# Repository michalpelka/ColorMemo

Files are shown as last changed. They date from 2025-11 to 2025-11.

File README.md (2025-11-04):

# ColorMemo


An open-source, handheld color memory game built around a WeMos D1 mini (ESP8266), a 3×4 push-button matrix, a 12‑pixel NeoPixel (WS2812) LED array, and a small buzzer. 
Power it up, memorize the brief color reveal, and then flip tiles two at a time to find matching pairs. Clear the board to win and enjoy the victory animation and melody.

## Photos

Below are a few snapshots of the prototype and assembly. Images are stored in `Photos/`.

<div align="center">
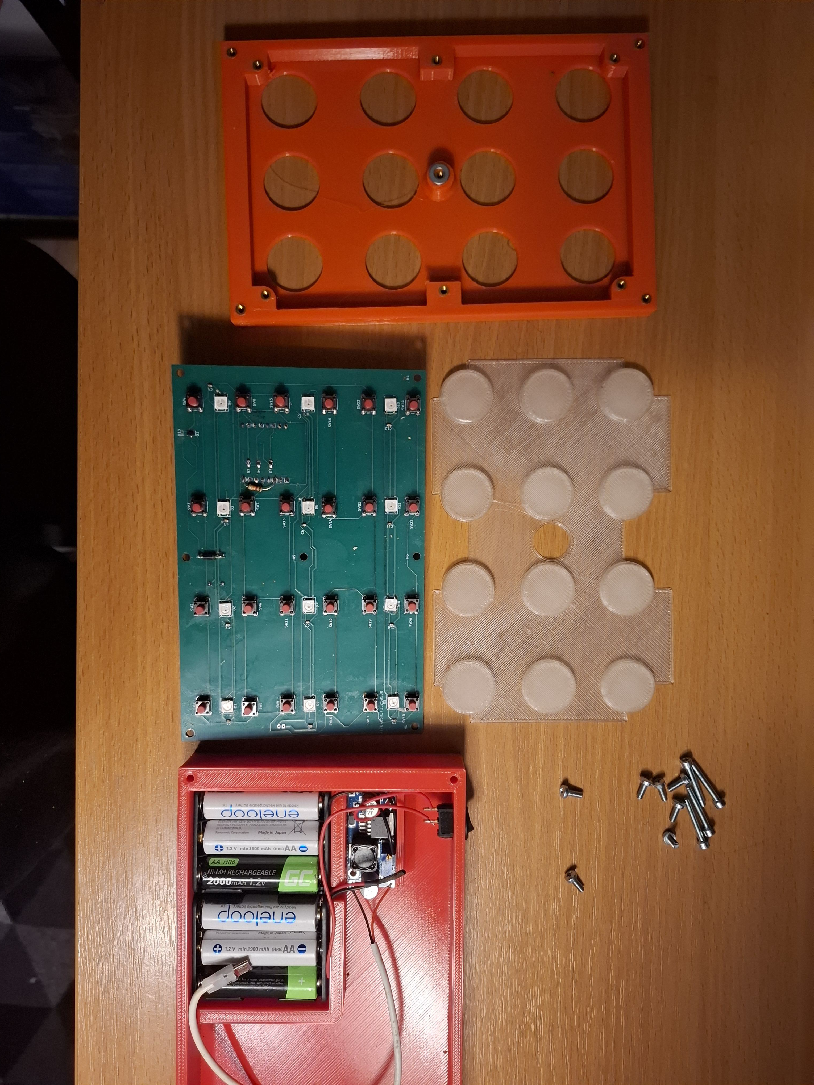
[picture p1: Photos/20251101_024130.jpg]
Assembly 2025-11-01 02:41
  
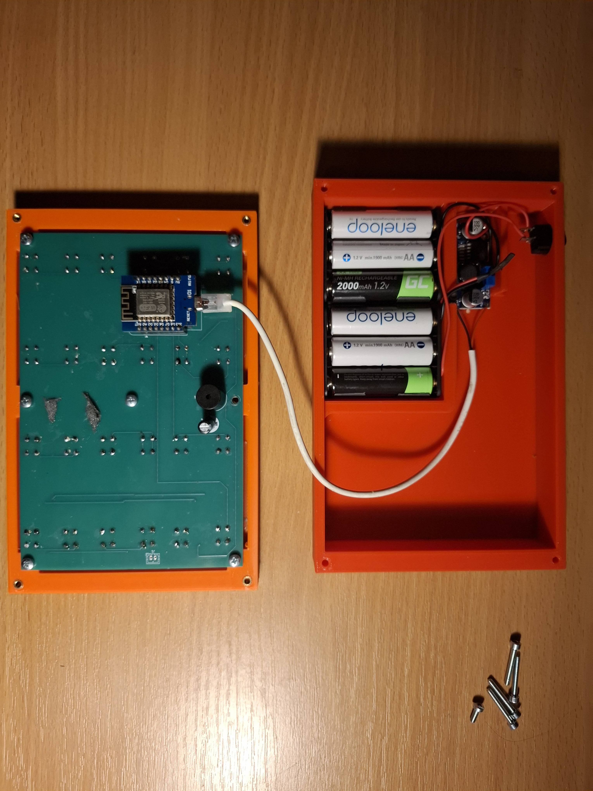
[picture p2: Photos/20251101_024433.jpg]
Assembly 2025-11-01 02:44
  
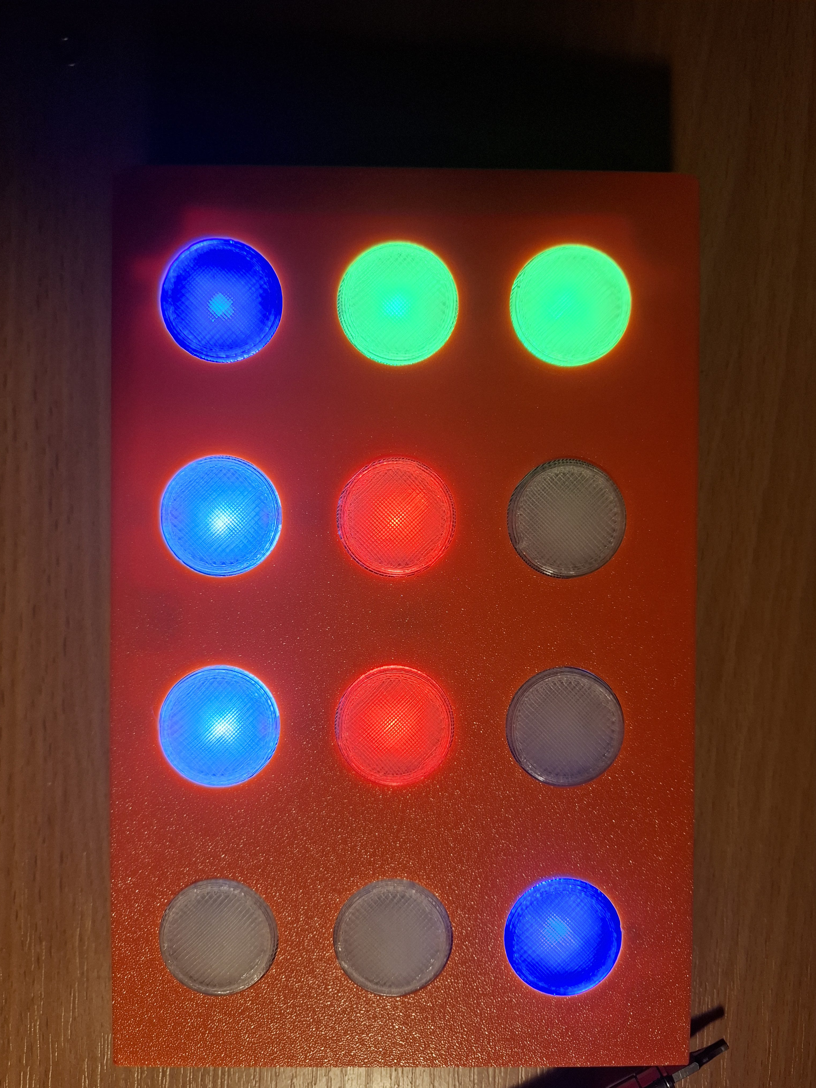
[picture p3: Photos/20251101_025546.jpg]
Assembly 2025-11-01 02:55
     
</div>

<div align="center">
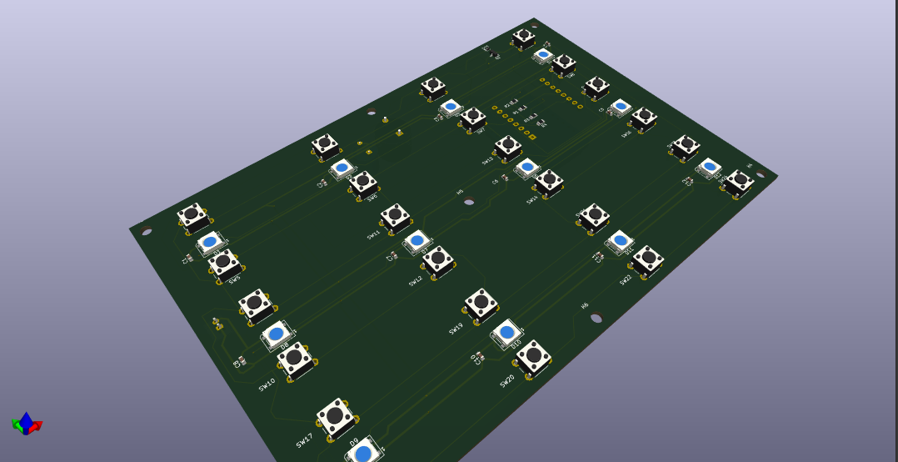
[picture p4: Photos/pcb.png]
  
</div>

## Repository structure

- `Firmware/` — PlatformIO project with Arduino firmware for ESP8266 (D1 mini lite) using Adafruit NeoPixel.
- `KiCad/` — Complete PCB design (schematic, PCB, STEP) and production files (`gerber/`).
- `3DPrint/` — 3D printable parts for enclosure and/or fixtures.
- `Cad/` — Additional mechanical CAD sources.
- `Photos/` — Renders or placement guides.
- `LICENSE` — Project license.

## Hardware overview

- MCU: WeMos D1 mini lite (ESP8266)
- LEDs: 12× WS2812/NeoPixel (strip or array)
- Inputs: 12 momentary push buttons arranged as a 3×4 matrix (row/column scanned)
- Audio: Passive buzzer for tones and win melody

The firmware scans a 3×4 button matrix while driving a 12‑LED NeoPixel strip. On boot, it shuffles 6 color pairs, briefly reveals all 12 tiles with tones, and then hides them. Press two buttons; if the colors match, they stay lit. Match all pairs to win.

### Pinout (D1 mini lite)

- NeoPixel DIN: D1 (GPIO5)
- Buzzer: D2 (GPIO4)
- Button matrix rows (outputs):
  - ROW0: D8 (GPIO15)
  - ROW1: D3 (GPIO0)
  - ROW2: D4 (GPIO2)
- Button matrix columns (inputs with pull‑ups):
  - COL0: D0 (GPIO16)
  - COL1: D7 (GPIO13)
  - COL2: D6 (GPIO12)
  - COL3: D5 (GPIO14)
- A0 (ADC) is sampled at boot to add entropy for shuffling.

Notes:
- Columns use `INPUT_PULLUP`; a pressed button reads LOW when its row is driven active (LOW).
- The firmware maps physical grid positions to LED indices to keep the visual grid coherent.

### Bill of materials (BOM)

- KiCad BOM
- 2x3AA battery holder
- Cheap step down LM965 
- USB cable to cut 

## Firmware

The firmware lives in `Firmware/` and is a PlatformIO project.

- Board environment: `d1_mini_lite`
- Platform: `espressif8266`
- Framework: `arduino`
- Dependency: `Adafruit NeoPixel`

### Quick start (PlatformIO CLI)

1. Install PlatformIO Core (CLI): https://platformio.org/install/cli
2. From the repository root (or `Firmware/`):
   - Build: `pio run -e d1_mini_lite`
   - Upload (adjust serial port if needed): `pio run -e d1_mini_lite -t upload`
   - Serial monitor (optional): `pio device monitor`

Alternatively, use the PlatformIO IDE extension in VS Code and pick the `d1_mini_lite` environment.

## PCB and fabrication

- Open `KiCad/ColorMemo/ColorMemo.kicad_pro` in KiCad 7+
- You need to handsolder 

## 3D printing

3MF are available in `./cad`. Source is available in OnShape https://cad.onshape.com/documents/b4ecd71daf39ea8c1ed2c249/w/92a4c2cfa870c08fc1134c94/e/b7d8f3f5da42c53fd1b61ef6.

## How to play

1. Power on: all 12 tiles briefly reveal colors with tones.
2. Press a button to reveal a tile; press a second button to reveal another.
3. If they match, both remain lit. If not, they hide after a short delay.
4. Match all pairs (6 pairs total) to trigger the win animation + melody.

## Project status

- Working prototype firmware and hardware files are present.

## License

This project is licensed under the terms in `LICENSE`.

## Acknowledgements

- Adafruit NeoPixel library (MIT): https://github.com/adafruit/Adafruit_NeoPixel
- PlatformIO ecosystem for painless embedded builds

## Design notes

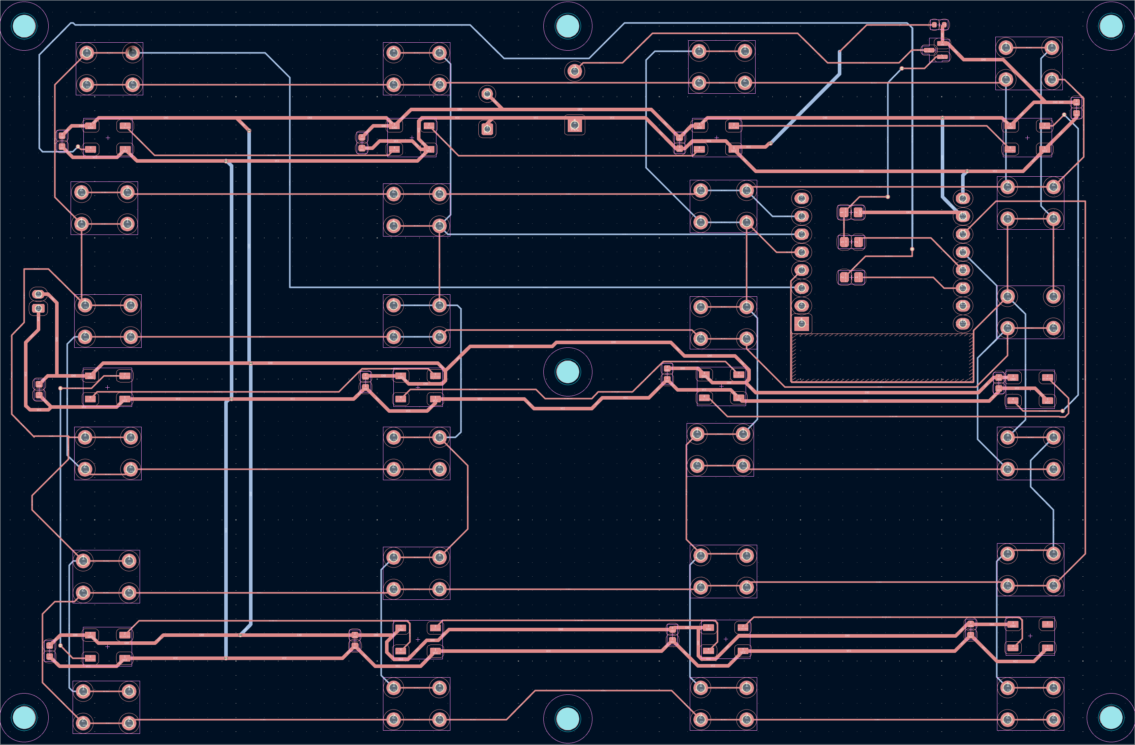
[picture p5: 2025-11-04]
Cad/PCB.png

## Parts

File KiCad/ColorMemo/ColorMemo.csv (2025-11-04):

Reference | Qty | Value | DNP | Exclude from BOM | Exclude from Board | Footprint | Datasheet
BZ1 | 1 | Buzzer |  |  |  | Buzzer_Beeper:Buzzer_12x9.5RM7.6 | ~
C1,C2,C3,C4,C5,C6,C7,C8,C9,C10,C11,C12 | 12 | 104 |  |  |  | Capacitor_SMD:C_0603_1608Metric | ~
C13 | 1 | C_Polarized |  |  |  | Capacitor_THT:CP_Radial_D8.0mm_P5.00mm | ~
D1,D2,D3,D4,D5,D6,D7,D8,D9,D10,D11,D12 | 12 | WS2812B |  |  |  | LED_SMD:LED_WS2812B_PLCC4_5.0x5.0mm_P3.2mm | https://cdn-shop.adafruit.com/datasheets/WS2812B.pdf
D13 | 1 | 1N4148WT |  |  |  | Diode_SMD:D_SOD-523 | https://www.diodes.com/assets/Datasheets/ds30396.pdf
H1,H2,H3,H4,H5,H6,H7 | 7 | MountingHole |  | Excluded from BOM |  | MountingHole:MountingHole_3.2mm_M3 | ~
J1 | 1 | Conn_01x02 |  |  |  | Connector_JST:JST_PH_B2B-PH-K_1x02_P2.00mm_Vertical | ~
Q1 | 1 | MMFTN3402 |  |  |  | Package_TO_SOT_SMD:SOT-23 | https://www.tme.eu/pl/details/mmftn3402-dio/tranzystory-z-kanalem-n-smd/diotec-semiconductor/mmftn3402/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
R1 | 1 | R100 |  |  |  | Resistor_SMD:R_0805_2012Metric_Pad1.20x1.40mm_HandSolder | ~
R2 | 1 | 100k |  |  |  | Resistor_SMD:R_0805_2012Metric_Pad1.20x1.40mm_HandSolder | ~
R3 | 1 | R330 |  |  |  | Resistor_SMD:R_0805_2012Metric_Pad1.20x1.40mm_HandSolder | ~
SW1,SW2,SW3,SW4,SW5,SW6,SW7,SW8,SW9,SW10,SW11,SW12,SW13,SW14,SW15,SW16,SW17,SW18,SW19,SW20,SW21,SW22,SW23,SW24 | 24 | SW_Push |  |  |  | Button_Switch_THT:SW_PUSH_6mm | ~
U1 | 1 | WEMOS_D1_mini |  |  |  | RF_Module:WEMOS_D1_mini_light | https://wiki.wemos.cc/products:d1:d1_mini#documentation

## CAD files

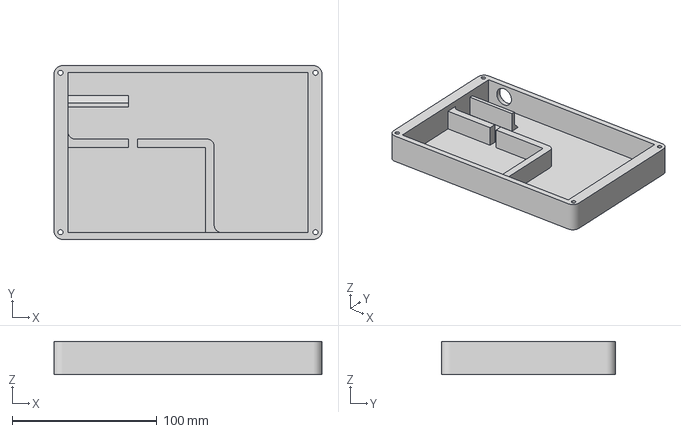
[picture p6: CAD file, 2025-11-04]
Cad/Bottom.3mf
185.0 x 120.0 x 23.0 mm

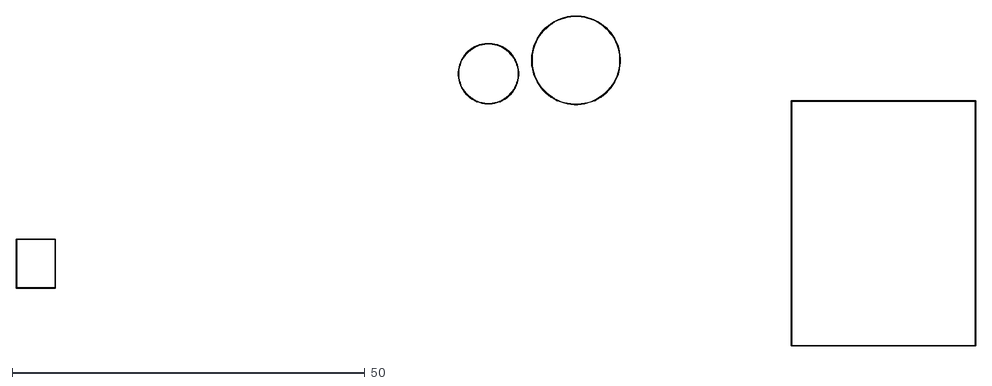
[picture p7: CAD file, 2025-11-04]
KiCad/ColorMemo/dxf/ColorMemo-B_Courtyard.dxf
136.0 x 46.7

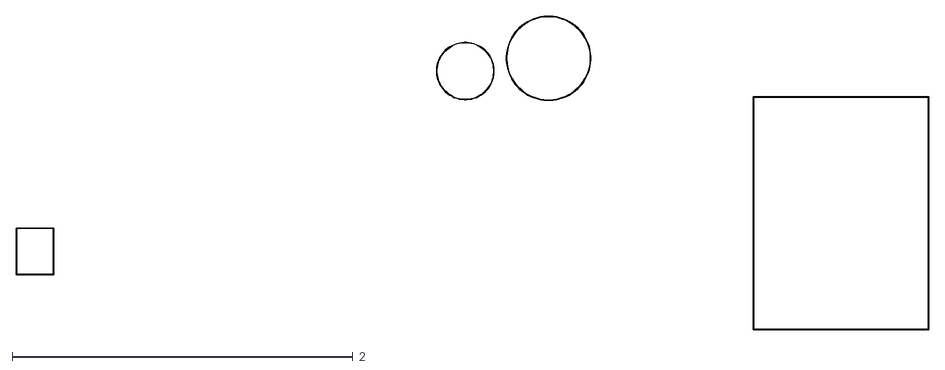
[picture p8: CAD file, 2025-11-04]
KiCad/ColorMemo/gerber/ColorMemo-B_Courtyard.dxf
5.35 x 1.84

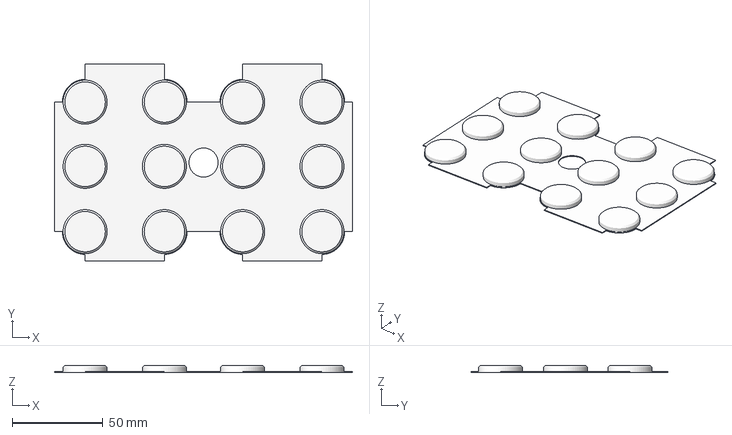
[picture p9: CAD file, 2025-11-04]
Cad/Keyboard.3mf
163.8 x 108.4 x 4.00 mm

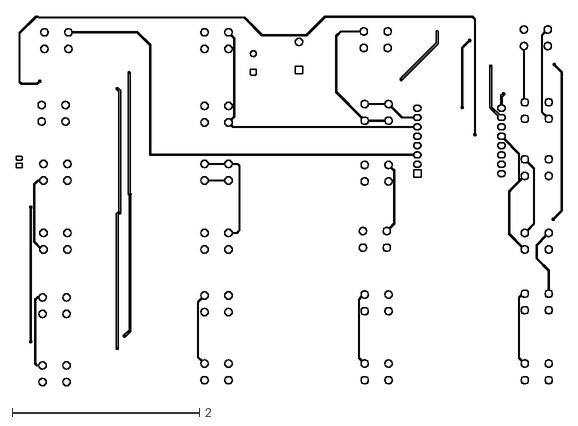
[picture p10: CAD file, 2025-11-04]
KiCad/ColorMemo/dxf/ColorMemo-B_Cu.dxf
5.84 x 3.95

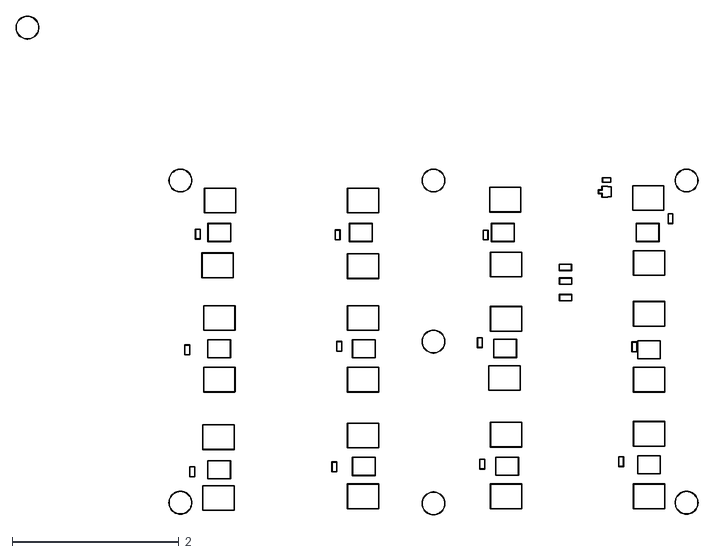
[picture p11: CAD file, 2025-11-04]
KiCad/ColorMemo/gerber/ColorMemo-F_Courtyard.dxf
8.17 x 5.97

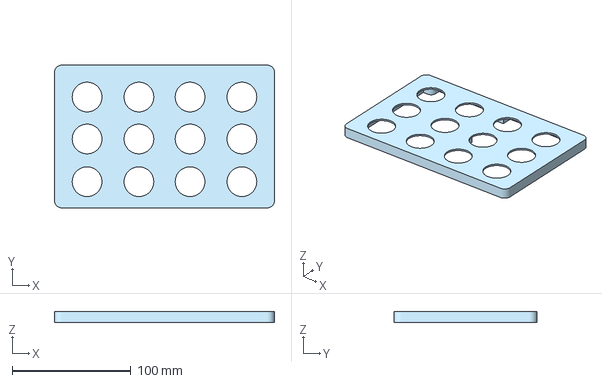
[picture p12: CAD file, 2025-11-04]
Cad/Topper.3mf
185.0 x 120.0 x 9.50 mm

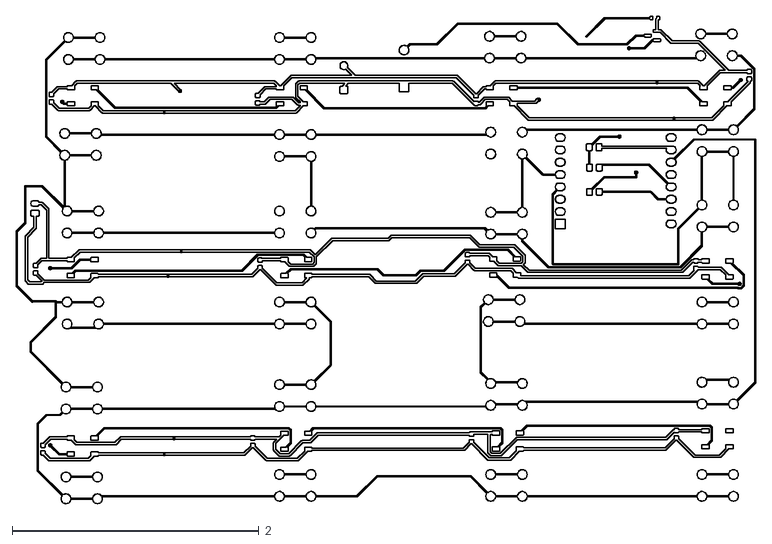
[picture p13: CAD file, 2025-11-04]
KiCad/ColorMemo/dxf/ColorMemo-F_Cu.dxf
6.00 x 3.95

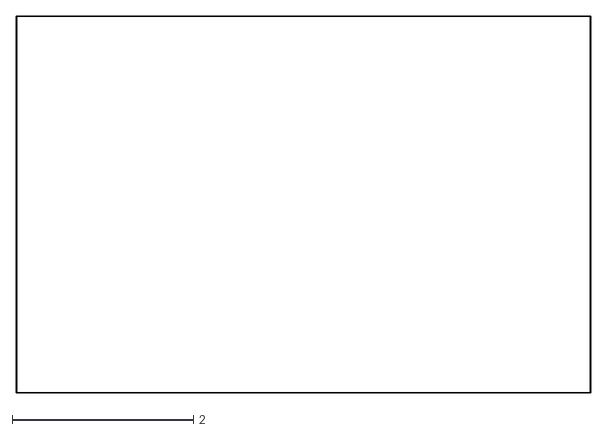
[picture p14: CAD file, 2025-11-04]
KiCad/ColorMemo/gerber/ColorMemo-Edge_Cuts.dxf
6.33 x 4.16

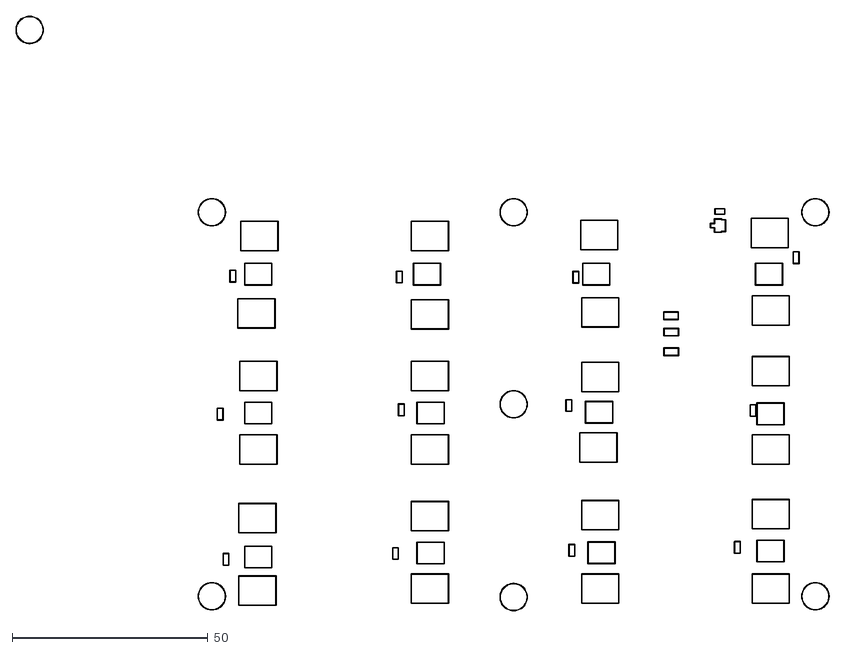
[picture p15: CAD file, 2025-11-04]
KiCad/ColorMemo/dxf/ColorMemo-F_Courtyard.dxf
207.5 x 151.7

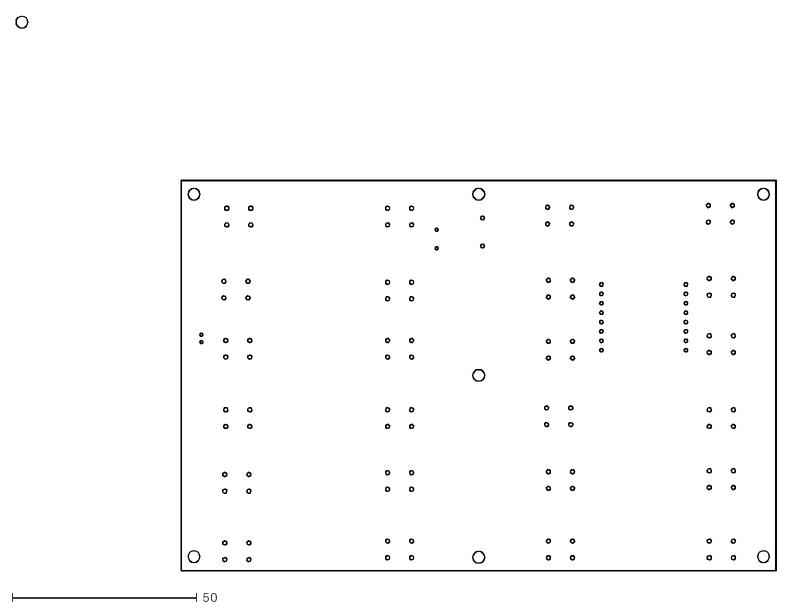
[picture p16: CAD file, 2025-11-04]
KiCad/ColorMemo/dxf/ColorMemo-Edge_Cuts.dxf
205.5 x 149.9

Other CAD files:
KiCad/ColorMemo/dxf/ColorMemo-B_Silkscreen.dxf
KiCad/ColorMemo/dxf/ColorMemo-F_Silkscreen.dxf
KiCad/ColorMemo/gerber/ColorMemo-B_Silkscreen.dxf
KiCad/ColorMemo/gerber/ColorMemo-F_Silkscreen.dxf

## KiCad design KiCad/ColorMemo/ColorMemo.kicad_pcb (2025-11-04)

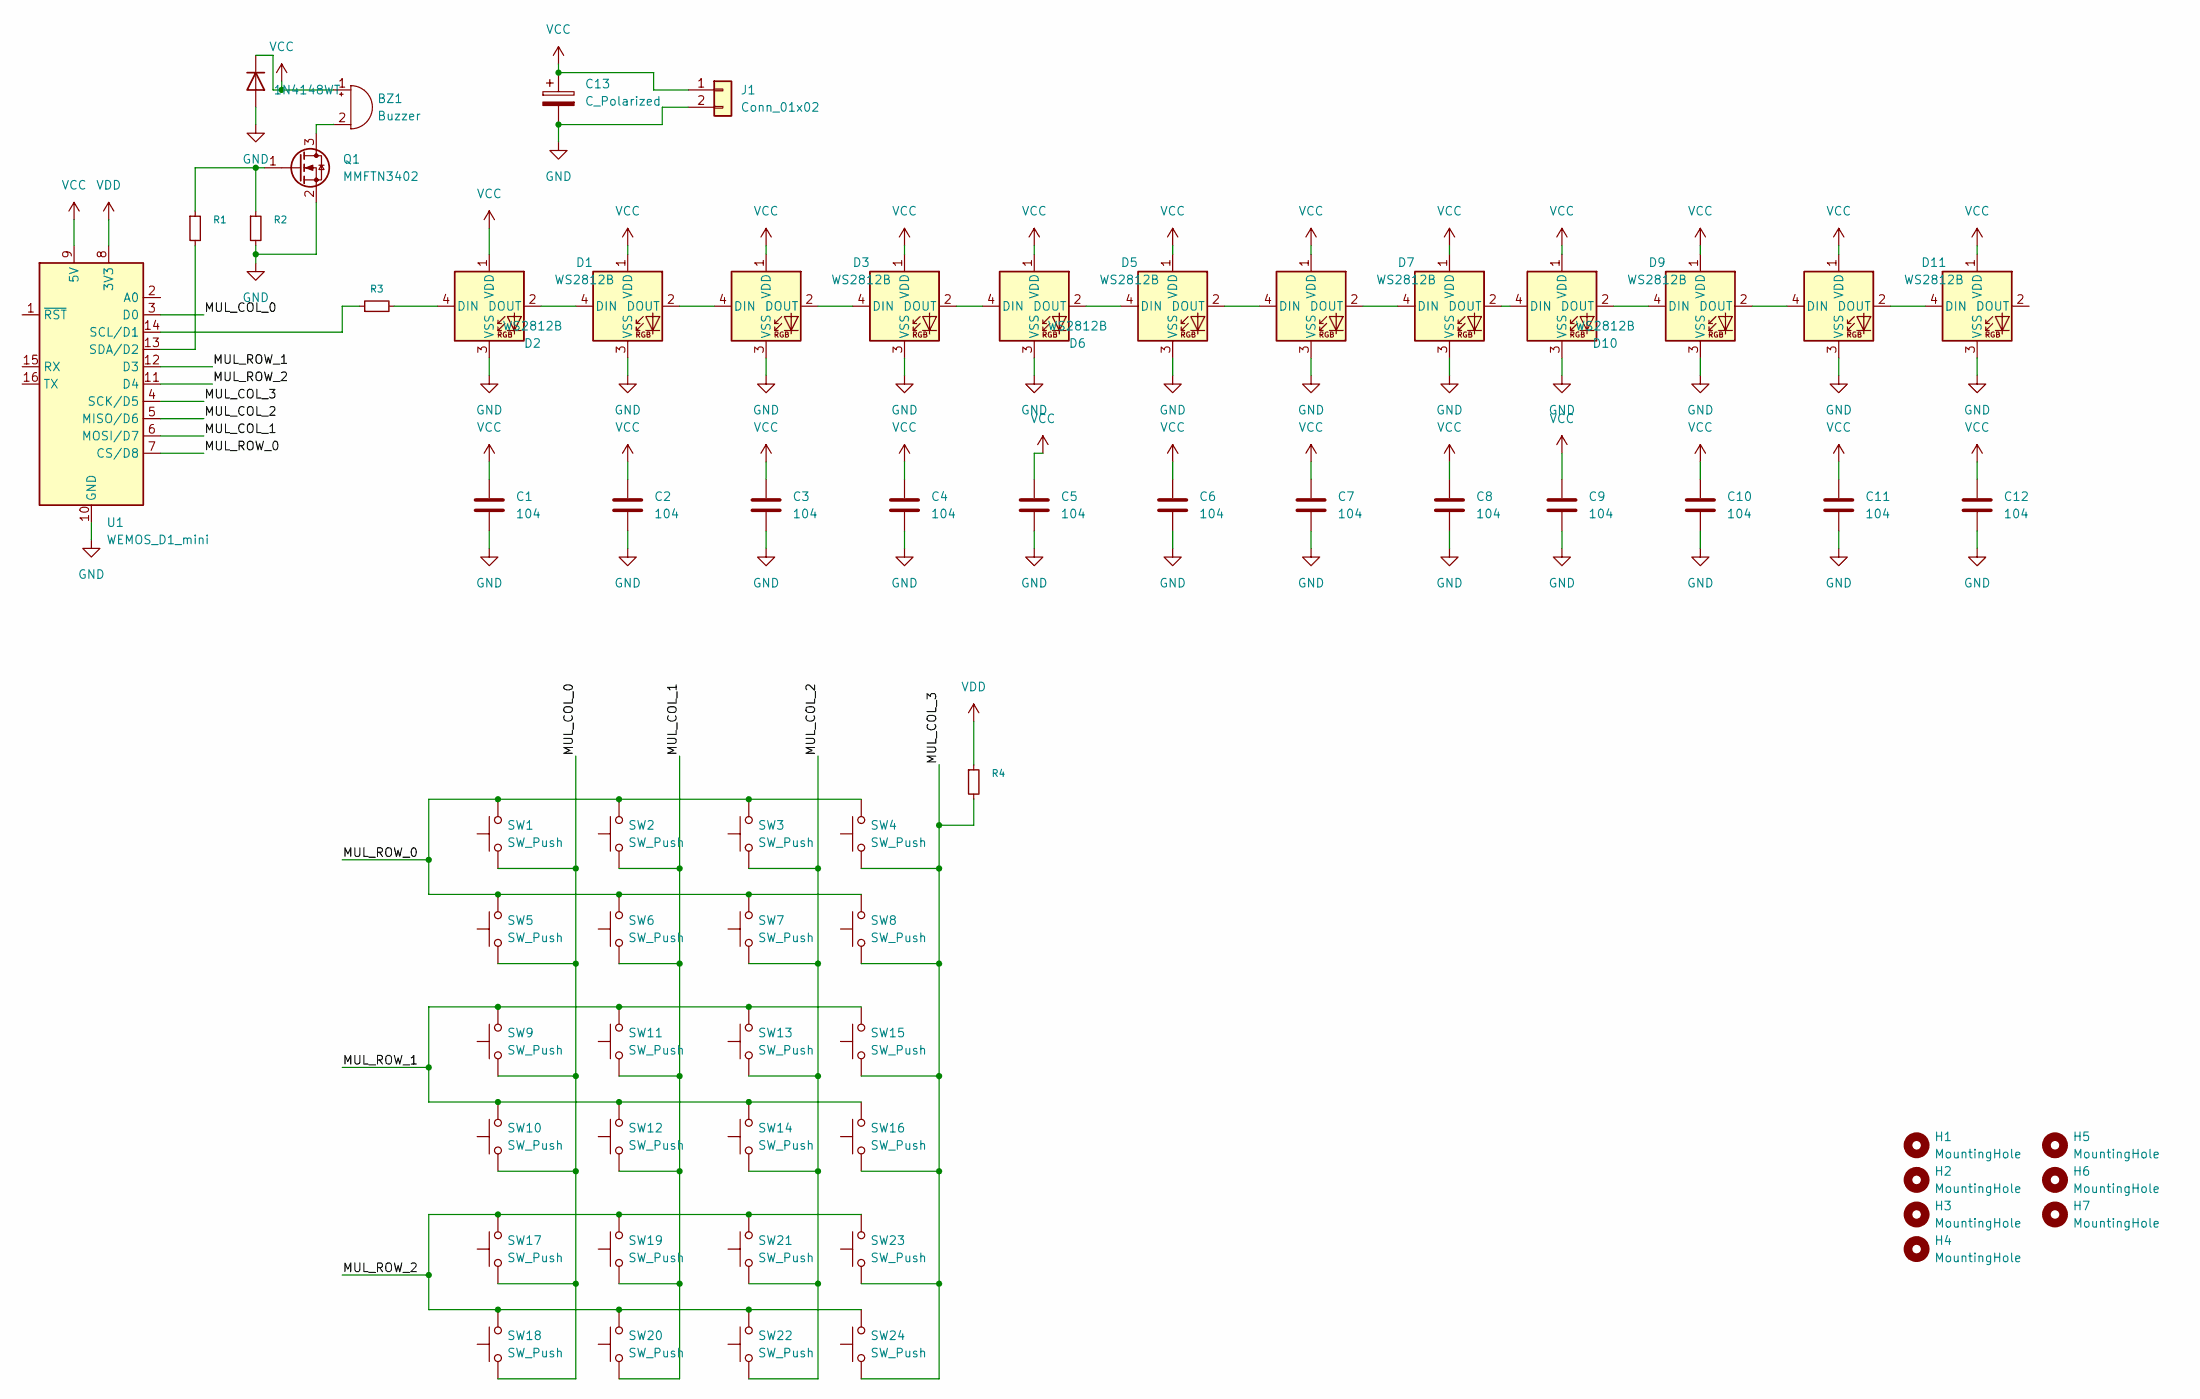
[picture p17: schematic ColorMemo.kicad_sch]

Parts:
BZ1: Buzzer; Buzzer_12x9.5RM7.6
C1, C2, C3, C4, C5, C6, C7, C8, C9, C10, C11, C12: 104; C_0603_1608Metric
C13: C_Polarized; CP_Radial_D8.0mm_P5.00mm
D1, D2, D3, D4, D5, D6, D7, D8, D9, D10, D11, D12: WS2812B; LED_WS2812B_PLCC4_5.0x5.0mm_P3.2mm
D13: 1N4148WT; D_SOD-523
H1, H2, H3, H4, H5, H6, H7: MountingHole; MountingHole_3.2mm_M3
J1: Conn_01x02; JST_PH_B2B-PH-K_1x02_P2.00mm_Vertical
Q1: MMFTN3402; SOT-23
R1: R100; R_0805_2012Metric_Pad1.20x1.40mm_HandSolder
R2: 100k; R_0805_2012Metric_Pad1.20x1.40mm_HandSolder
R3: R330; R_0805_2012Metric_Pad1.20x1.40mm_HandSolder
R4: 10k; R_0805_2012Metric_Pad1.20x1.40mm_HandSolder
SW1, SW2, SW3, SW4, SW5, SW6, SW7, SW8, SW9, SW10, SW11, SW12, SW13, SW14, SW15, SW16, SW17, SW18, SW19, SW20, SW21, SW22, SW23, SW24: SW_Push; SW_PUSH_6mm
U1: WEMOS_D1_mini; WEMOS_D1_mini_light

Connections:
/MUL_COL_0: SW1.1, SW5.1, SW9.1, SW10.1, SW17.1, SW18.1, U1.3 (D0)
/MUL_COL_1: SW2.1, SW6.1, SW11.1, SW12.1, SW19.1, SW20.1, U1.6 (MOSI/D7)
/MUL_COL_2: SW3.1, SW7.1, SW13.1, SW14.1, SW21.1, SW22.1, U1.5 (MISO/D6)
/MUL_COL_3: R4.2, SW4.1, SW8.1, SW15.1, SW16.1, SW23.1, SW24.1, U1.4 (SCK/D5)
/MUL_ROW_0: SW1.2, SW2.2, SW3.2, SW4.2, SW5.2, SW6.2, SW7.2, SW8.2, U1.7 (CS/D8)
/MUL_ROW_1: SW9.2, SW10.2, SW11.2, SW12.2, SW13.2, SW14.2, SW15.2, SW16.2, U1.12 (D3)
/MUL_ROW_2: SW17.2, SW18.2, SW19.2, SW20.2, SW21.2, SW22.2, SW23.2, SW24.2, U1.11 (D4)
GND: C1.2, C2.2, C3.2, C4.2, C5.2, C6.2, C7.2, C8.2, C9.2, C10.2, C11.2, C12.2, C13.2, D1.3 (VSS), D2.3 (VSS), D3.3 (VSS), D4.3 (VSS), D5.3 (VSS), D6.3 (VSS), D7.3 (VSS), D8.3 (VSS), D9.3 (VSS), D10.3 (VSS), D11.3 (VSS), D12.3 (VSS), D13.2 (A), J1.2, Q1.2 (S), R2.2, U1.10 (GND)
unnamed: BZ1.2 (-), Q1.3 (D)
unnamed: D1.4 (DIN), R3.2
unnamed: D1.2 (DOUT), D2.4 (DIN)
unnamed: D2.2 (DOUT), D3.4 (DIN)
unnamed: D3.2 (DOUT), D4.4 (DIN)
unnamed: D4.2 (DOUT), D5.4 (DIN)
unnamed: D5.2 (DOUT), D6.4 (DIN)
unnamed: D6.2 (DOUT), D7.4 (DIN)
unnamed: D7.2 (DOUT), D8.4 (DIN)
unnamed: D8.2 (DOUT), D9.4 (DIN)
unnamed: D9.2 (DOUT), D10.4 (DIN)
unnamed: D10.2 (DOUT), D11.4 (DIN)
unnamed: D11.2 (DOUT), D12.4 (DIN)
unnamed: Q1.1 (G), R1.1, R2.1
unnamed: R3.1, U1.14 (SCL/D1)
unnamed: R1.2, U1.13 (SDA/D2)
VCC: BZ1.1 (+), C1.1, C2.1, C3.1, C4.1, C5.1, C6.1, C7.1, C8.1, C9.1, C10.1, C11.1, C12.1, C13.1, D1.1 (VDD), D2.1 (VDD), D3.1 (VDD), D4.1 (VDD), D5.1 (VDD), D6.1 (VDD), D7.1 (VDD), D8.1 (VDD), D9.1 (VDD), D10.1 (VDD), D11.1 (VDD), D12.1 (VDD), D13.1 (K), J1.1, U1.9 (5V)
VDD: R4.1, U1.8 (3V3)

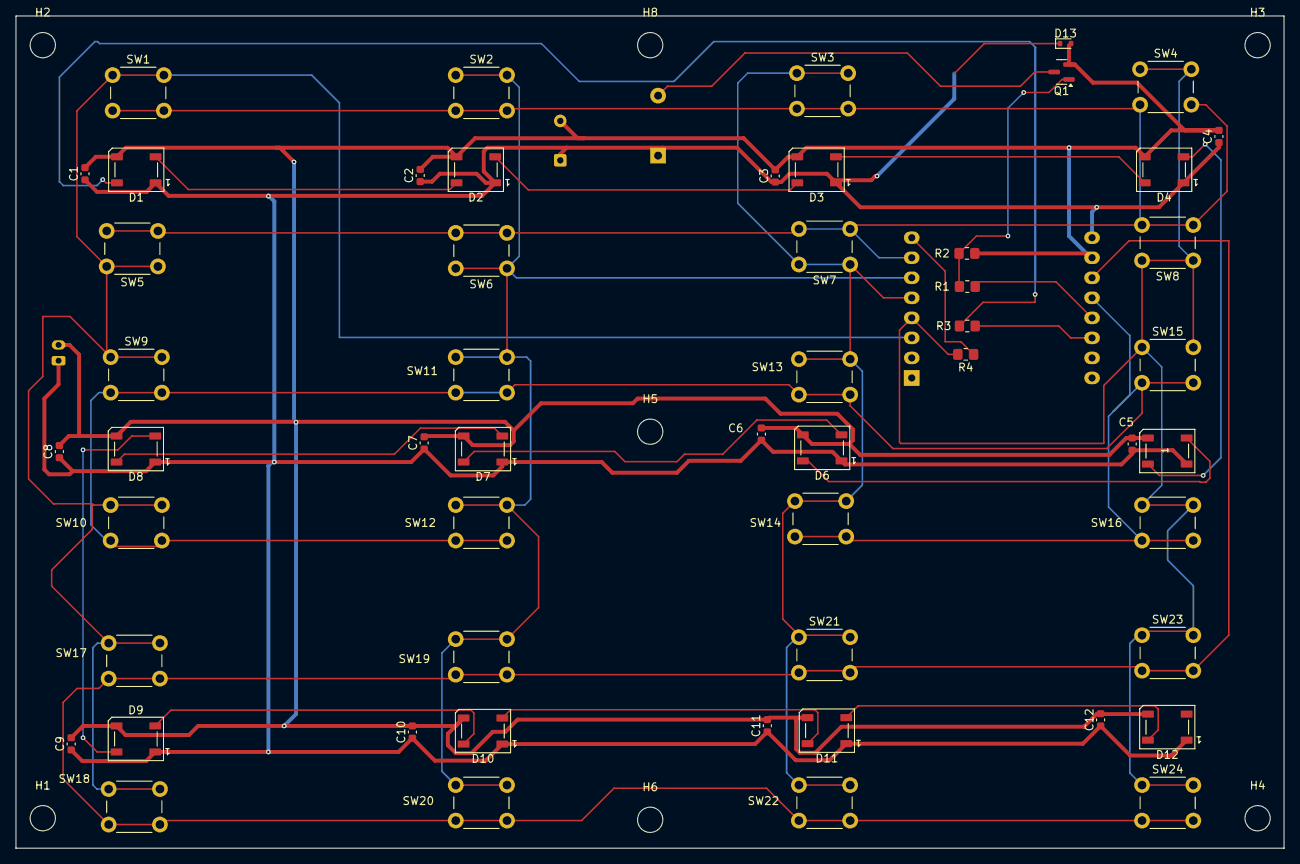
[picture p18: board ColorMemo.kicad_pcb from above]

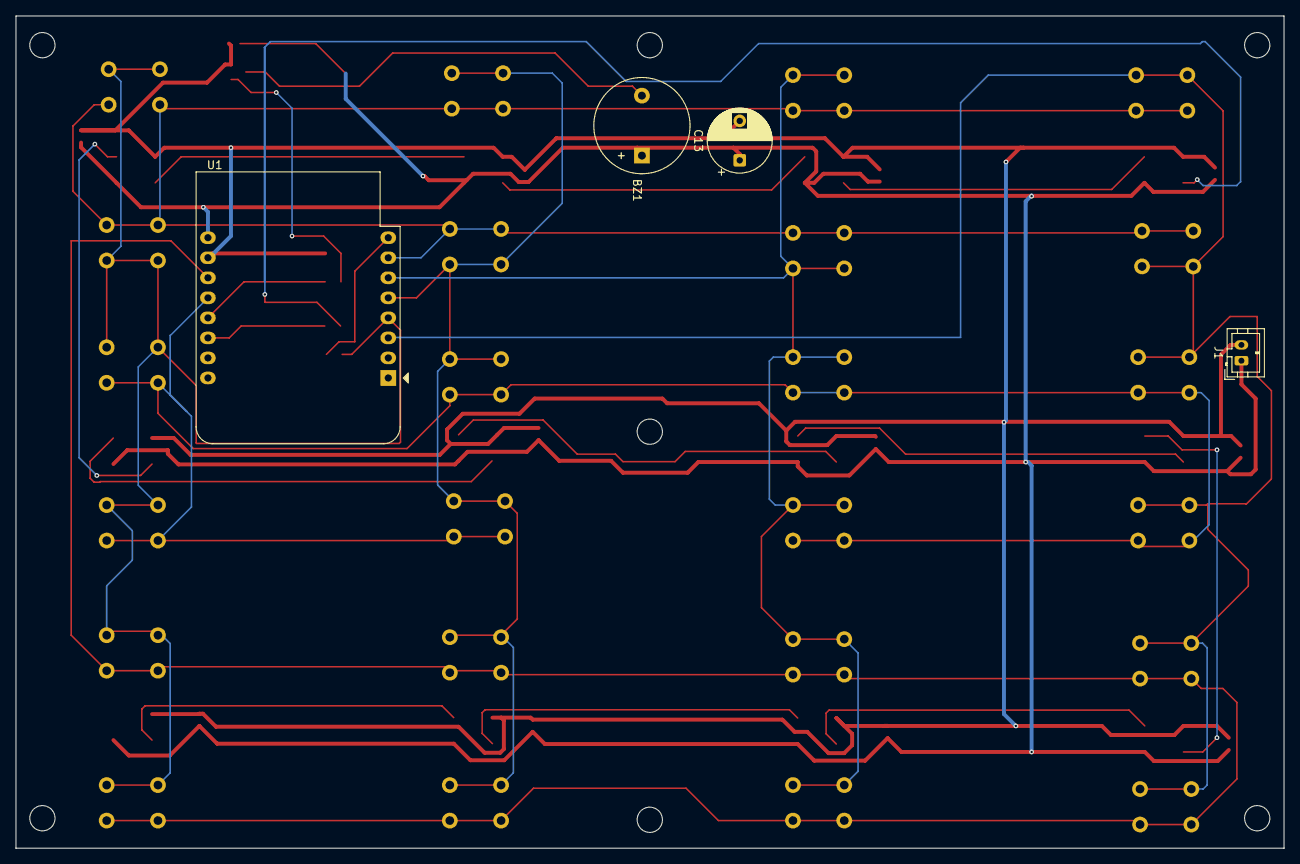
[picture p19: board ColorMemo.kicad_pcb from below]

Board: 2 copper layers, 160.8 x 105.5 mm, 66 parts (4 on the bottom side), 26 nets.

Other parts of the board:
H8: MountingHole; MountingHole_3.2mm_M3

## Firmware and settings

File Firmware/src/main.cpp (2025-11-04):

#include <Arduino.h>
#include <Adafruit_NeoPixel.h>

#define LED_PIN   D1        // GPIO5 on WeMos D1
#define BUZZER_PIN D2 
#define NUM_LEDS  12        // change to your strip length

#define MUL_ROW_0 D8
#define MUL_ROW_1 D3
#define MUL_ROW_2 D4

#define MUL_COL_0 D0
#define MUL_COL_1 D7
#define MUL_COL_2 D6
#define MUL_COL_3 D5



const uint8_t ROWS = 3;
const uint8_t COLS = 4;

const uint8_t PixelToLedIndxMap[ROWS][COLS] = {
  {0, 1, 2, 3},
  {7, 6, 5, 4},
  {8, 9, 10, 11}
};

const uint8_t RowPins[ROWS] = {MUL_ROW_0, MUL_ROW_1, MUL_ROW_2};
const uint8_t colPins[COLS] = {MUL_COL_0, MUL_COL_1, MUL_COL_2, MUL_COL_3};

// Use NEO_GRBW for RGBW chips (4 channels per pixel) + NEO_KHZ800 for timing
Adafruit_NeoPixel strip(NUM_LEDS, LED_PIN, NEO_GRB + NEO_KHZ800);
const uint8_t RED[4]   = {255, 0, 0, 0};
const uint8_t GREEN[4] = {0, 255, 0, 0};
const uint8_t BLUE[4]  = {0, 0, 255, 0};
const uint8_t PURPLE[4] = {128, 0, 128, 0};
const uint8_t YELLOW[4] = {255, 255, 0, 0};
const uint8_t CYAN[4]   = {0, 255, 255, 0};
const uint8_t WHITE[4] = {255, 255, 255, 0};

const uint8_t ORANGE[4] = {255, 165, 0, 0};
const uint8_t HOTPINK[4] = {255, 105, 180, 0};
const uint8_t MAGENTA[4] = {255, 0, 255, 0};
const uint8_t VIOLET[4]  = {238, 130, 238, 0};
const uint8_t PINK[4]    = {255, 192, 203, 0};

const uint8_t OFF[4]   = {0, 0, 0, 0};

const uint8_t ColorCount = 6;
const uint8_t* COLORS[ColorCount] = {RED, GREEN, BLUE, PURPLE, YELLOW, WHITE};

const unsigned int TONES[ColorCount] = {261, 329, 392, 523, 659, 784}; // C4, E4, G4, C5, E5, G5, C6

struct Pixel{
  uint8_t m_buttonStateRaw = LOW;
  uint8_t const * m_color = nullptr;
};

Pixel pixels[ROWS][COLS];


void swap(uint8_t &a, uint8_t &b) {
  uint8_t temp = a;
  a = b;
  b = temp;
}

void shuffleArray(uint8_t *array, size_t n) {
  for (size_t i = n - 1; i > 0; i--) {
    size_t j = random(0, i + 1); // pick random index 0..i
    swap(array[i], array[j]);
  }
}


void renderPixelState(){

  // render pixel state to stip


  for (uint8_t r = 0; r < ROWS; r++) {
    for (uint8_t c = 0; c < COLS; c++) {
      uint8_t idx = PixelToLedIndxMap[r][c];
      if (pixels[r][c].m_color == nullptr) {
        strip.setPixelColor(idx, OFF[0], OFF[1], OFF[2], OFF[3]);
        continue;
      }
      strip.setPixelColor(idx, pixels[r][c].m_color[0], pixels[r][c].m_color[1], pixels[r][c].m_color[2], pixels[r][c].m_color[3]);
    }
  }
  strip.show();
}
static uint32_t ColorToGuess[ROWS][COLS];


unsigned long randomSeed() {
  unsigned long seed = 0;
  for (int i = 0; i < 32; i++) {
    seed ^= (analogRead(A0) & 0x01) << i; // use only least significant bit
    delay(1); // small delay so noise changes
  }
  return seed ^ millis(); // also mix in timer
}


void ClearDisplay() {
  for (uint8_t r = 0; r < ROWS; r++) {
    for (uint8_t c = 0; c < COLS; c++) {
      pixels[r][c].m_color = nullptr;
    }
  }
  renderPixelState();
}
void setup() {
  // Serial.begin(9600);
  // Serial.println();
  // Serial.println("Memory Info:");

  // Serial.printf("Free Sketch space: %d\n", ESP.getFreeSketchSpace());
  // Serial.printf("CPU Frequency: %d MHz\n", ESP.getCpuFreqMHz());
  // Serial.printf("Chip ID: %06X\n", ESP.getChipId());
  // Serial.printf("Flash Chip ID: %06X\n", ESP.getFlashChipId());

  // setup buzzer pin
  pinMode(BUZZER_PIN, OUTPUT);
  digitalWrite(BUZZER_PIN, LOW);

  
  //setup cols pins to digital input with pull-down resistors
  for (uint8_t c = 0; c < COLS; c++) {
    pinMode(colPins[c], INPUT_PULLUP);
  }
  // setup rows pins to output
  for (uint8_t r = 0; r < ROWS; r++) {
    pinMode(RowPins[r], OUTPUT);
    digitalWrite(RowPins[r], HIGH); // set all rows to HIGH (not active)
  }

  strip.begin();
  strip.setBrightness(180);
  strip.show();

  pixels[0][0].m_color = RED;
  pixels[0][1].m_color = RED;
  pixels[0][2].m_color = RED;
  pixels[0][3].m_color = RED;

  pixels[1][0].m_color = GREEN;
  pixels[1][1].m_color = GREEN;
  pixels[1][2].m_color = GREEN;
  pixels[1][3].m_color = GREEN;

  pixels[2][0].m_color = BLUE;
  pixels[2][1].m_color = BLUE;
  pixels[2][2].m_color = BLUE;
  pixels[2][3].m_color = BLUE;

  renderPixelState();

  // clear all pixels
  for (uint8_t r = 0; r < ROWS; r++) {
    for (uint8_t c = 0; c < COLS; c++) {
      pixels[r][c].m_color = nullptr;
      pixels[r][c].m_buttonStateRaw = LOW;
    }
  }
  // Init game
  // randomize seed
  int seed = randomSeed();
  randomSeed(seed);
  

  uint8_t colorIndexes [2*ColorCount];
  for (uint8_t i = 0; i < 2*ColorCount; i++) {
    colorIndexes[i] = i;
  }
  shuffleArray(colorIndexes, 2*ColorCount);

  for (uint8_t r = 0; r < ROWS; r++) {
    for (uint8_t c = 0; c < COLS; c++) {
      const uint8_t pixelIndex = r*COLS + c;
      uint8_t colorIndex = colorIndexes[pixelIndex] % ColorCount;
      ColorToGuess[r][c] = colorIndex;
    }
  }

  for (uint8_t r = 0; r < ROWS; r++) {
    for (uint8_t c = 0; c < COLS; c++) {
        pixels[r][c].m_color = COLORS[ColorToGuess[r][c]];
        tone(BUZZER_PIN, TONES[ColorToGuess[r][c]], 150);
        renderPixelState();
        delay(100);
    }
  }
  delay(500);
  ClearDisplay();


}

struct RowCol {
  uint8_t row = 255;
  uint8_t col = 255;
  void reset() {
    row = 255;
    col = 255;
  }
  bool isSet() const {
    return row != 255 && col != 255;
  }
};

void BlockingTone(uint8_t pin, unsigned int frequency, unsigned long duration) {
  // update the display
  renderPixelState();
  delay(10);
  tone(pin, frequency);
  delay(duration + 20);
  noTone(pin);
}

Pixel& getPixel(const RowCol &rc) {
  return pixels[rc.row][rc.col];
}


const unsigned int animationWinSteps [12][ROWS][COLS] = {
  {
    {1, 0, 0, 0},
    {0, 0, 0, 0},
    {0, 0, 0, 0}
  },
  {
    {1, 1, 0, 0},
    {0, 0, 0, 0},
    {0, 0, 0, 0}
  },
  {
    {1, 1, 1, 0},
    {0, 0, 0, 0},
    {0, 0, 0, 0}
  },
   {
    {1, 1, 1, 1},
    {0, 0, 0, 0},
    {0, 0, 0, 0}
  },
   {
    {1, 1, 1, 1},
    {1, 0, 0, 0},
    {0, 0, 0, 0}
   },
   {
    {1, 1, 1, 1},
    {1, 1, 0, 0},
    {0, 0, 0, 0}
   },
   {
    {1, 1, 1, 1},
    {1, 1, 1, 0},
    {0, 0, 0, 0}
   },
   {
    {1, 1, 1, 1},
    {1, 1, 1, 1},
    {0, 0, 0, 0}
   },
   {
    {1, 1, 1, 1},
    {1, 1, 1, 1},
    {1, 0, 0, 0}
   },
   {
    {1, 1, 1, 1},
    {1, 1, 1, 1},
    {1, 1 ,0 ,0}
   },
   {
    {1 ,1 ,1 ,1},
    {1 ,1 ,1 ,1},
    {1 ,1 ,1 ,0}
   },
   {
    {1 ,1 ,1 ,1},
    {1 ,1 ,1 ,1},
    {1 ,1 ,1 ,1}
   }
};

void DisplayStep(const unsigned int step[ROWS][COLS]) {
  for (uint8_t r = 0; r < ROWS; r++) {
    for (uint8_t c = 0; c < COLS; c++) {
      if (step[r][c] == 1) {
        pixels[r][c].m_color = COLORS[ColorToGuess[r][c]];
      } else {
        pixels[r][c].m_color = nullptr;
      }
    }
  }
  renderPixelState();
}

void WinAnim(){
  ClearDisplay(); 
  // play melody

  const unsigned int melody[12] = {523, 659, 784, 1046, 784, 659, 523, 392, 523, 659, 784, 1046}; // C5 E5 G5 C6 G5 E5 C5 G4 C5 E5 G5 C6
  const unsigned int noteDurations[12] = {150, 150, 150, 300, 150, 150, 300, 150, 150, 150, 150, 300};

  for (uint8_t i = 0; i < 12; i++) {
    DisplayStep(animationWinSteps[i]);
    BlockingTone(BUZZER_PIN, melody[i], noteDurations[i]);
  }
  ClearDisplay();
  setup();

}

void OnButtonPress(uint8_t row, uint8_t col) {
  static RowCol firstPick;
  static RowCol secondPick;
  if (pixels[row][col].m_color != nullptr) {
    // already revealed
    return;
  }
  
  // FIRST PICK
  if (!firstPick.isSet() && !secondPick.isSet()) {
    // both picks are set, reset
   firstPick = {row, col};
   getPixel(firstPick).m_color = COLORS[ColorToGuess[row][col]];
   BlockingTone(BUZZER_PIN, TONES[ColorToGuess[row][col]], 100);

   return;
  }

  // SECOND PICK
  if (firstPick.isSet() && !secondPick.isSet()) {
    if (firstPick.row == row && firstPick.col == col) {
      // same pixel, ignore
      return;
    }
    secondPick = {row, col};
    getPixel(secondPick).m_color = COLORS[ColorToGuess[row][col]];
 
    BlockingTone(BUZZER_PIN, TONES[ColorToGuess[row][col]], 100);
    // check for match
    if (ColorToGuess[firstPick.row][firstPick.col] == ColorToGuess[secondPick.row][secondPick.col]) {
  
      // match, leave revealed
      firstPick.reset();
      secondPick.reset();
      if (std::all_of(&pixels[0][0], &pixels[0][0] + ROWS*COLS, [](const Pixel &p){ return p.m_color != nullptr; })) {
        // all pixels revealed, win
        WinAnim();
        WinAnim();
        WinAnim();
      }
  
    } else {
      // no match, hide after delay
      delay(1000);
      getPixel(firstPick).m_color = nullptr;
      getPixel(secondPick).m_color = nullptr;
      firstPick.reset();
      secondPick.reset();
    }
    renderPixelState();
  }

  // check for matches

}

void loop() {
  static uint8_t currentRow = 2;
  for (uint8_t r = 0; r < ROWS; r++) {
    digitalWrite(RowPins[r], (r == currentRow) ? LOW : HIGH);
  }

  // read columns
  for (uint8_t c = 0; c < COLS; c++) {
    uint8_t buttonState = digitalRead(colPins[c]);
   
    if (buttonState != pixels[currentRow][c].m_buttonStateRaw) {
      // button state changed
      pixels[currentRow][c].m_buttonStateRaw = buttonState;
      if (buttonState == LOW) {
        OnButtonPress(currentRow, c);
        
        //pixels[currentRow][c].m_color = WHITE;
      }
    }
  }
  //Serial.printf("Row %d c1 : %d c2 : %d c3 : %d c4 : %d\n", currentRow, digitalRead(colPins[0]), digitalRead(colPins[1]), digitalRead(colPins[2]), digitalRead(colPins[3]));
  currentRow = (currentRow + 1) % ROWS;

  renderPixelState();

  

}

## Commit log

2025-09-28 added kicad project
    [ColorMemo.kicad_pcb, ColorMemo.kicad_sch, Locations.dxf]
2025-09-29 order to jlcpcb
    [ColorMemo-B_Cu.gbr, ColorMemo-B_Mask.gbr, ColorMemo-B_Paste.gbr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]
2025-11-04 Added readme, CAD
    [Bottom.3mf, ColorMemo-B_Courtyard.dxf, ColorMemo-B_Cu.dxf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]
